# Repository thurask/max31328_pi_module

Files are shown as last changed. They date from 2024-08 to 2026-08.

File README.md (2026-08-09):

# MAX31328-based RTC module for Raspberry Pi

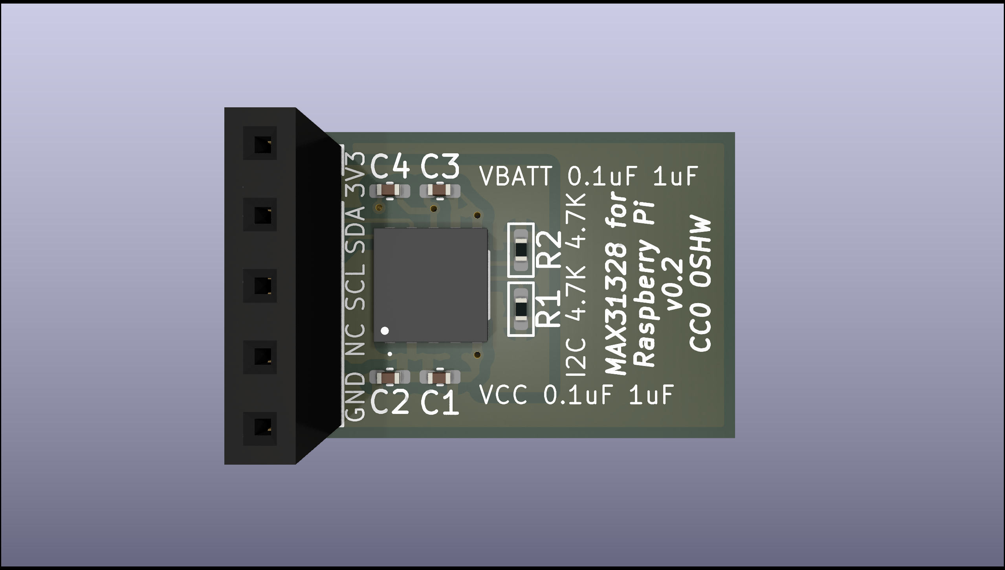
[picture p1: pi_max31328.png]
Render of the board


## Rationale
The MAX31328 is the updated (and cheaper!) refresh of the venerable DS3231 RTC chip, although there's very few MAX31328 based time modules for Pi, and even fewer in the tiny footprint of the usual Aliexpress special RTC module. Also I wanted to learn KiCAD some more. :)

## Installation
In your /boot/firmware/config.txt file add the line ```dtoverlay=i2c-rtc,ds3231``` at the end, then turn the Pi off. Plug the 5 pin header into GPIO pins 1, 3, 5, 7 and 9 (+3V3, SDA, SDL, not connected, GND, respectively), then turn it back on. If it worked, you should see something happen when running ``hwclock -w``. Since the MAX31328 is a drop-in replacement for the DS3231 you may notice that these instructions are the same as any RTC module using that particular chip.

## Building the PCB
Import project files into KiCad 10 and export to your PCB manufacturing service of choice, or just use the files in the grbl subfolder.

## BOM
1. MAX31328: the star of the show, accept no substitutes. 
2. Battery holder: Keystone Electronics 3030. This takes CR927 or CR1025 non-rechargeable 3V lithium coin cells. Not as compact as the RTC modules with the bare tabs soldered on the board, but you can replace the battery on this one without breaking out the soldering iron.
3. I2C pullups: two 4.7 kΩ 0805 resistors, although I think you can get away with using the Pi's built in I2C pullups. Still, belt and braces.
4. Decoupling caps: two pairs of 1μF + 0.1μF 0805 capacitors, one pair for VCC (the Pi, closer to the GND pin) and the other pair for VBATT (the battery, closer to the 3V3 pin).
5. Pin headers: right angle or straight, just as long as it'll fit onto the Pi's GPIO pins. Standard 2.54mm pitch.

## Contributing
Feel free to do what you like with this; build it, change it, fix it, sell it, whatever. If you do make improvements it'd be super cool to make those publicly available.

## License
[CC0-1.0](LICENSE)

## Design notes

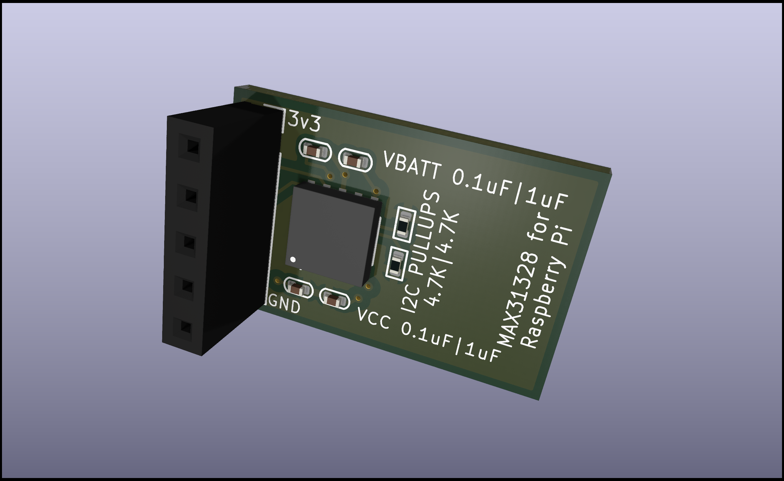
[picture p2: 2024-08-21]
0.1/pi_max31328.png

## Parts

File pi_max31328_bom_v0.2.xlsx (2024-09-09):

Item # | *Designator | *Qty | Manufacturer | *Mfg Part # | Description / Value | *Package/Footprint | Type | Your Instructions / Notes
1 | U1 | 1 | Analog Devices/Maxim | MAX31328NELB+ | Real Time Clock (RTC) IC Clock/Calendar I2C 10-LLGA | 10-LGA | SMD
2 | J1 | 1 | Adam Tech | RS1-05-G | 5 Position Receptacle Connector 0.100" (2.54mm) Through Hole Gold | 5POS | THT | Substitutions: Wurth Elektronik 61300511821; Samtec SSW-105-01-G-S; Samtec SSQ-105-01-G-S; Samtec SSQ-105-02-G-S; Zhouri PM2.54-1*5
3 | BAT1 | 1 | Keystone Electronics | 3030 | Battery Holder (Open) Coin, 10.0mm 1 Cell SMD (SMT) Tab | 3POS | SMD | Substitutions: Keystone Electronics 3050(TR)
4 | C1, C3 | 2 | Murata | GRM155Z71A105KE01J | 1 µF ±10% 10V Ceramic Capacitor X7R 0402 (1005 Metric) | 0402 | SMD | Substitutions: Murata GRM155Z71A105KE01D; Kyocera AVX KAM05CR71A105KH; Cal-Chip GMC04X7R105K10NT; Murata GCM155C71A105KE38J; TDK C1005X7S1A105K050BC; Samsung CL05Y105KP6VPNC
5 | C2, C4 | 2 | Murata | GRM155R71C104KA88D | 0.1 µF ±10% 16V Ceramic Capacitor X7R 0402 (1005 Metric) | 0402 | SMD | Substitutions: Murata GRM155R71C104KA88J; YAGEO CC0402KRX7R7BB104; Samsung CL05B104K05NNNC; Kemet C0402C104K4RAC7867; Kyocera AVX KGM05AR71C104KH; Wurth Elektronik 885012205037
6 | R1, R2 | 2 | Vishay | CRCW04024K70FKED | 4.7 kOhms ±1% 0.063W, 1/16W Chip Resistor 0402 (1005 Metric) Automotive AEC-Q200 Thick Film | 0402 | SMD | Substitutions: Vishay RCS04024K70FKED; KOA Speer SG73P1EWTTP4701F; Panasonic ERJ-PA2F4701X; Rohm ESR01MZPF4701; YAGEO SR0402FR-7T4K7L

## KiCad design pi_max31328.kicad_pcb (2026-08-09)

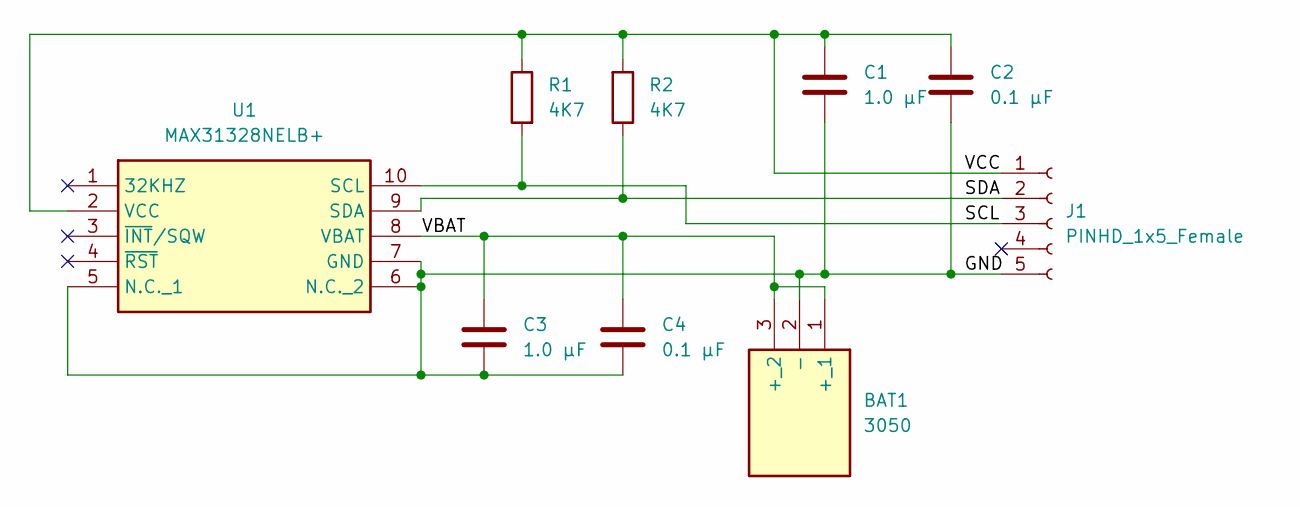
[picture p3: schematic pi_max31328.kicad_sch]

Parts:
BAT1: 3050; Mouser Part Number 534-3050
C1, C3: 1.0 μF; C_0805_2012Metric
C2, C4: 0.1 μF; C_0805_2012Metric
J1: PINHD_1x5_Female; PinSocket_1x05_P2.54mm_Vertical
R1, R2: 4K7; R_0805_2012Metric
U1: MAX31328NELB+; MAX31328NELB; Mouser Part Number 700-MAX31328NELB+

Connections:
/GND: BAT1.2 (-), C1.2, C2.2, C3.2, C4.2, J1.5, U1.5 (N.C._1), U1.6 (N.C._2), U1.7 (GND)
/SCL: J1.3, R1.1, U1.10 (SCL)
/SDA: J1.2, R2.2, U1.9 (SDA)
/VBAT: BAT1.1 (+_1), BAT1.3 (+_2), C3.1, C4.1, U1.8 (VBAT)
/VCC: C1.1, C2.1, J1.1, R1.2, R2.1, U1.2 (VCC)

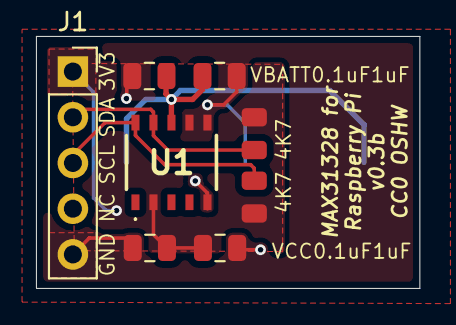
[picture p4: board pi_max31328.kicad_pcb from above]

Board: 2 copper layers, 21.3 x 14.0 mm, 9 parts (1 on the bottom side), 5 nets.

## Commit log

2026-08-09 kicad 10
    [pi_max31328-B_Cu.gbr, pi_max31328-B_Mask.gbr, pi_max31328-B_Paste.gbr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]
2026-08-09 untracked files, readme
    [pi_max31328-NPTH-drl_map.gbr, pi_max31328-PTH-drl_map.gbr]
